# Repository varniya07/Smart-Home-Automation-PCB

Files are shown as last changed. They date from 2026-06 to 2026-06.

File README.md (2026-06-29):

# 🏠 Smart Home Automation PCB

<p align="center">
  
  
  
  
</p>

---

# 📖 Overview

This project is a custom-designed **ESP32-based Smart Home Automation PCB** created using **KiCad 9**.

The board integrates an ESP32 microcontroller with an AC-to-DC power supply, voltage regulation, relay driver circuit, UART programming interface, and user controls for reliable IoT-based home automation.

---

# ✨ Features

- ESP32-WROOM-32 Microcontroller
- HLK-PM03 AC to DC Converter
- AMS1117-3.3V Voltage Regulator
- Relay Driver Circuit
- Boot & Reset Buttons
- UART Programming Header
- Two-Layer PCB
- Compact Board Layout
- Mounting Holes

---

# 🛠 Software Used

- KiCad 9
- Git
- GitHub

---

# 🔩 Hardware Components

- ESP32-WROOM-32
- HLK-PM03 AC-DC Module
- AMS1117-3.3V
- Relay
- BC817 Transistor
- LEDs
- Resistors
- Capacitors
- Push Buttons
- UART Header

---

# 📷 Schematic

<p align="center">

</p>

---

# 📷 PCB Layout

<p align="center">
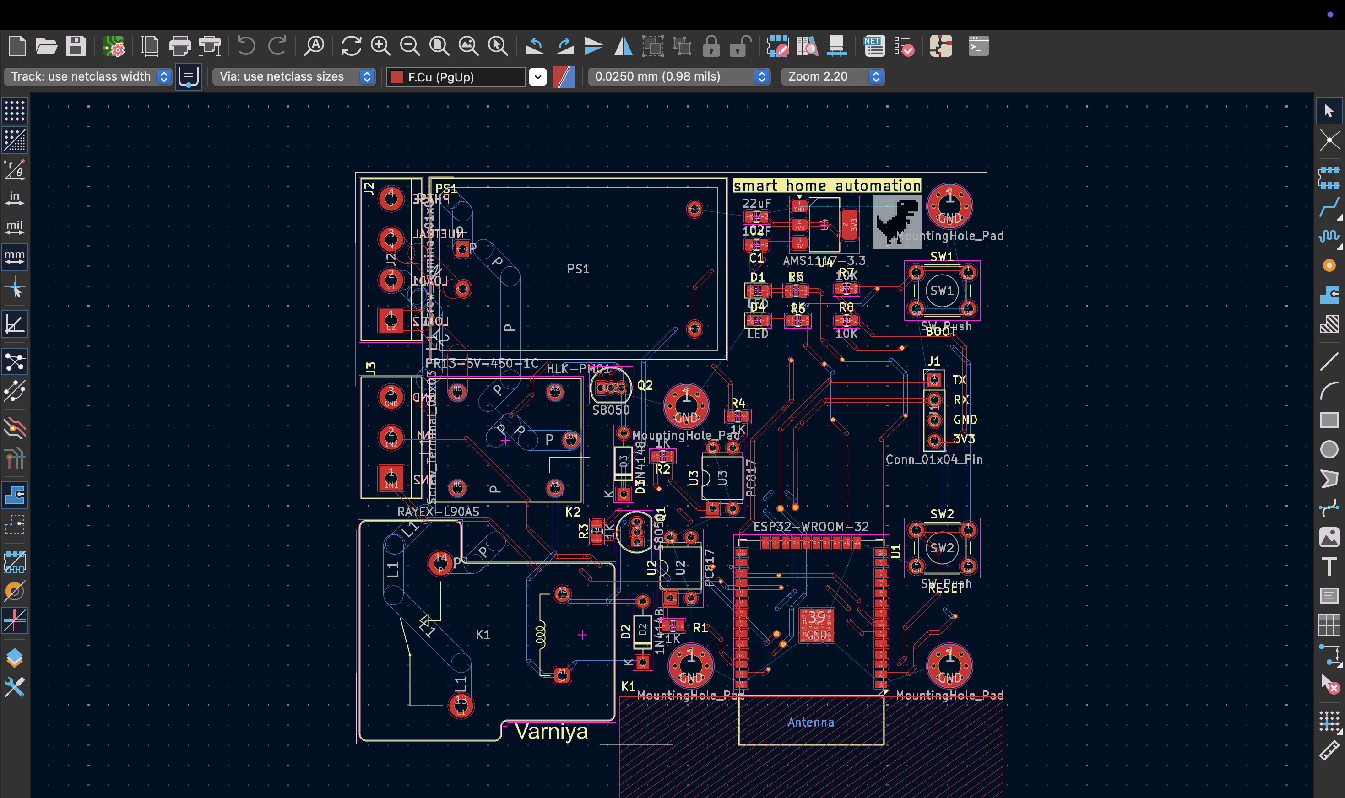
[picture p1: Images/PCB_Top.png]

</p>

---

# 📷 3D PCB View

<p align="center">
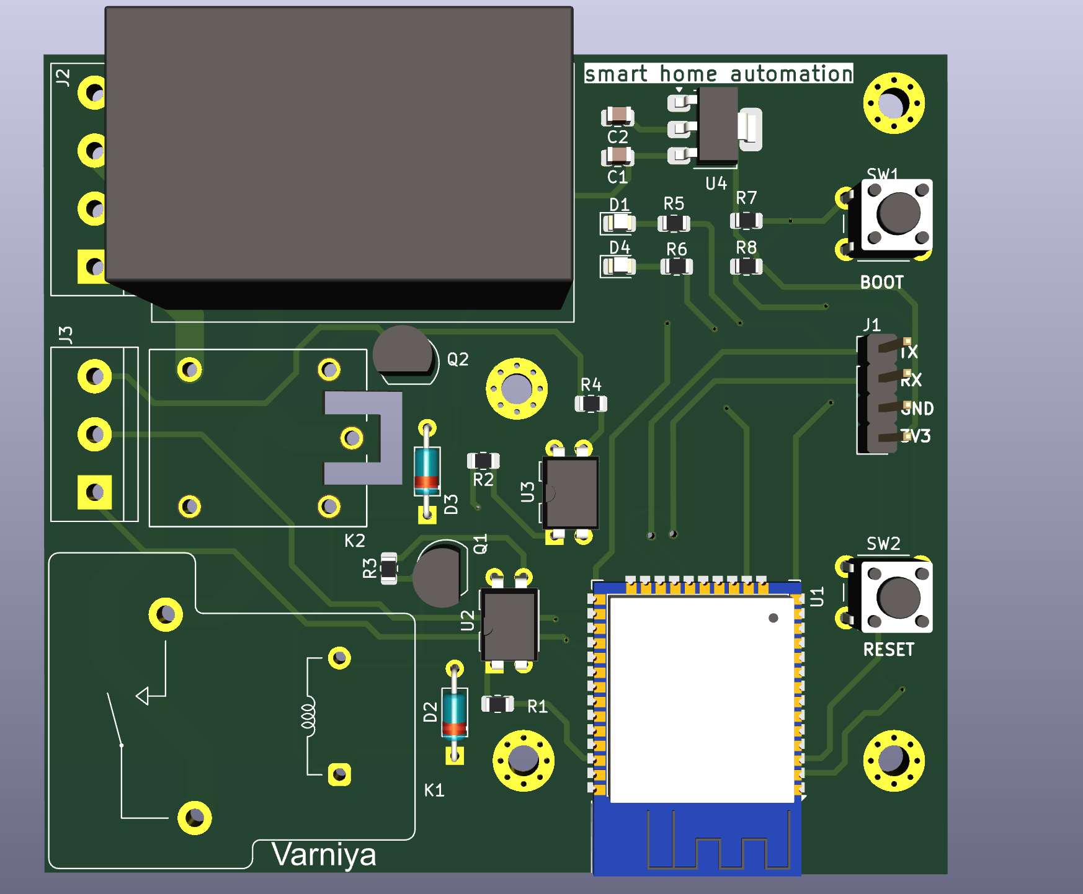
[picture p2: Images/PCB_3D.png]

</p>

---

# ⚙️ Working Principle

1. The AC mains supply is converted into regulated DC using the **HLK-PM03 AC-DC converter**.
2. The **AMS1117-3.3V** regulator provides a stable 3.3V supply for the ESP32.
3. The ESP32 receives commands through Wi-Fi.
4. GPIO pins control the relay driver transistor.
5. The relay switches external electrical appliances.
6. Boot and Reset buttons simplify programming and debugging.
7. The UART header enables firmware uploading and serial monitoring.

---

# 📂 Repository Structure

```text
Smart-Home-Automation-PCB
│
├── BOM/
│
├── Gerber/
│
├── Images/
│   ├── PCB_Top.png
│   ├── PCB_3D.png
│   └── smart home automation.svg
│
├── KiCad_Project/
│   ├── smart home automation.kicad_pcb
│   ├── smart home automation.kicad_pro
│   ├── smart home automation.kicad_prl
│   ├── smart home automation.kicad_sch
│   └── smart home automation-backups
│
└── README.md
```

---

# 📦 Gerber Files

The complete Gerber package required for PCB manufacturing is included in the **Gerber** folder.

Supported manufacturers include:

- JLCPCB
- PCBWay
- ALLPCB
- NextPCB

---

# 🚀 Applications

- Smart Home Automation
- IoT Systems
- Embedded Systems
- ESP32 Development
- PCB Design Learning
- Electronics Education

---

# 📚 Skills Demonstrated

- PCB Design using KiCad
- Schematic Capture
- Component Selection
- PCB Routing
- Design Rule Check (DRC)
- Gerber File Generation
- PCB Manufacturing Preparation
- Embedded Hardware Design

---

# 🔮 Future Improvements

- MQTT Integration
- Mobile Application
- Energy Monitoring
- OTA Firmware Updates
- Current & Voltage Sensing
- Voice Assistant Integration
- Smart Scheduling

---

# 👩‍💻 Author

## Varniya Bhatnagar

**B.E. Electronics & Communication Engineering**  
Panjab University

### Connect with me

- 📧 Email: **varniyaece@gmail.com**
- 💼 LinkedIn: https://www.linkedin.com/in/varniya-bhatnagar-1ab361327/
- 🐙 GitHub: https://github.com/varniya07

---

## ⭐ Support

If you found this project useful, consider giving it a ⭐ and following my GitHub profile for more Electronics, PCB Design, Embedded Systems, and VLSI projects.

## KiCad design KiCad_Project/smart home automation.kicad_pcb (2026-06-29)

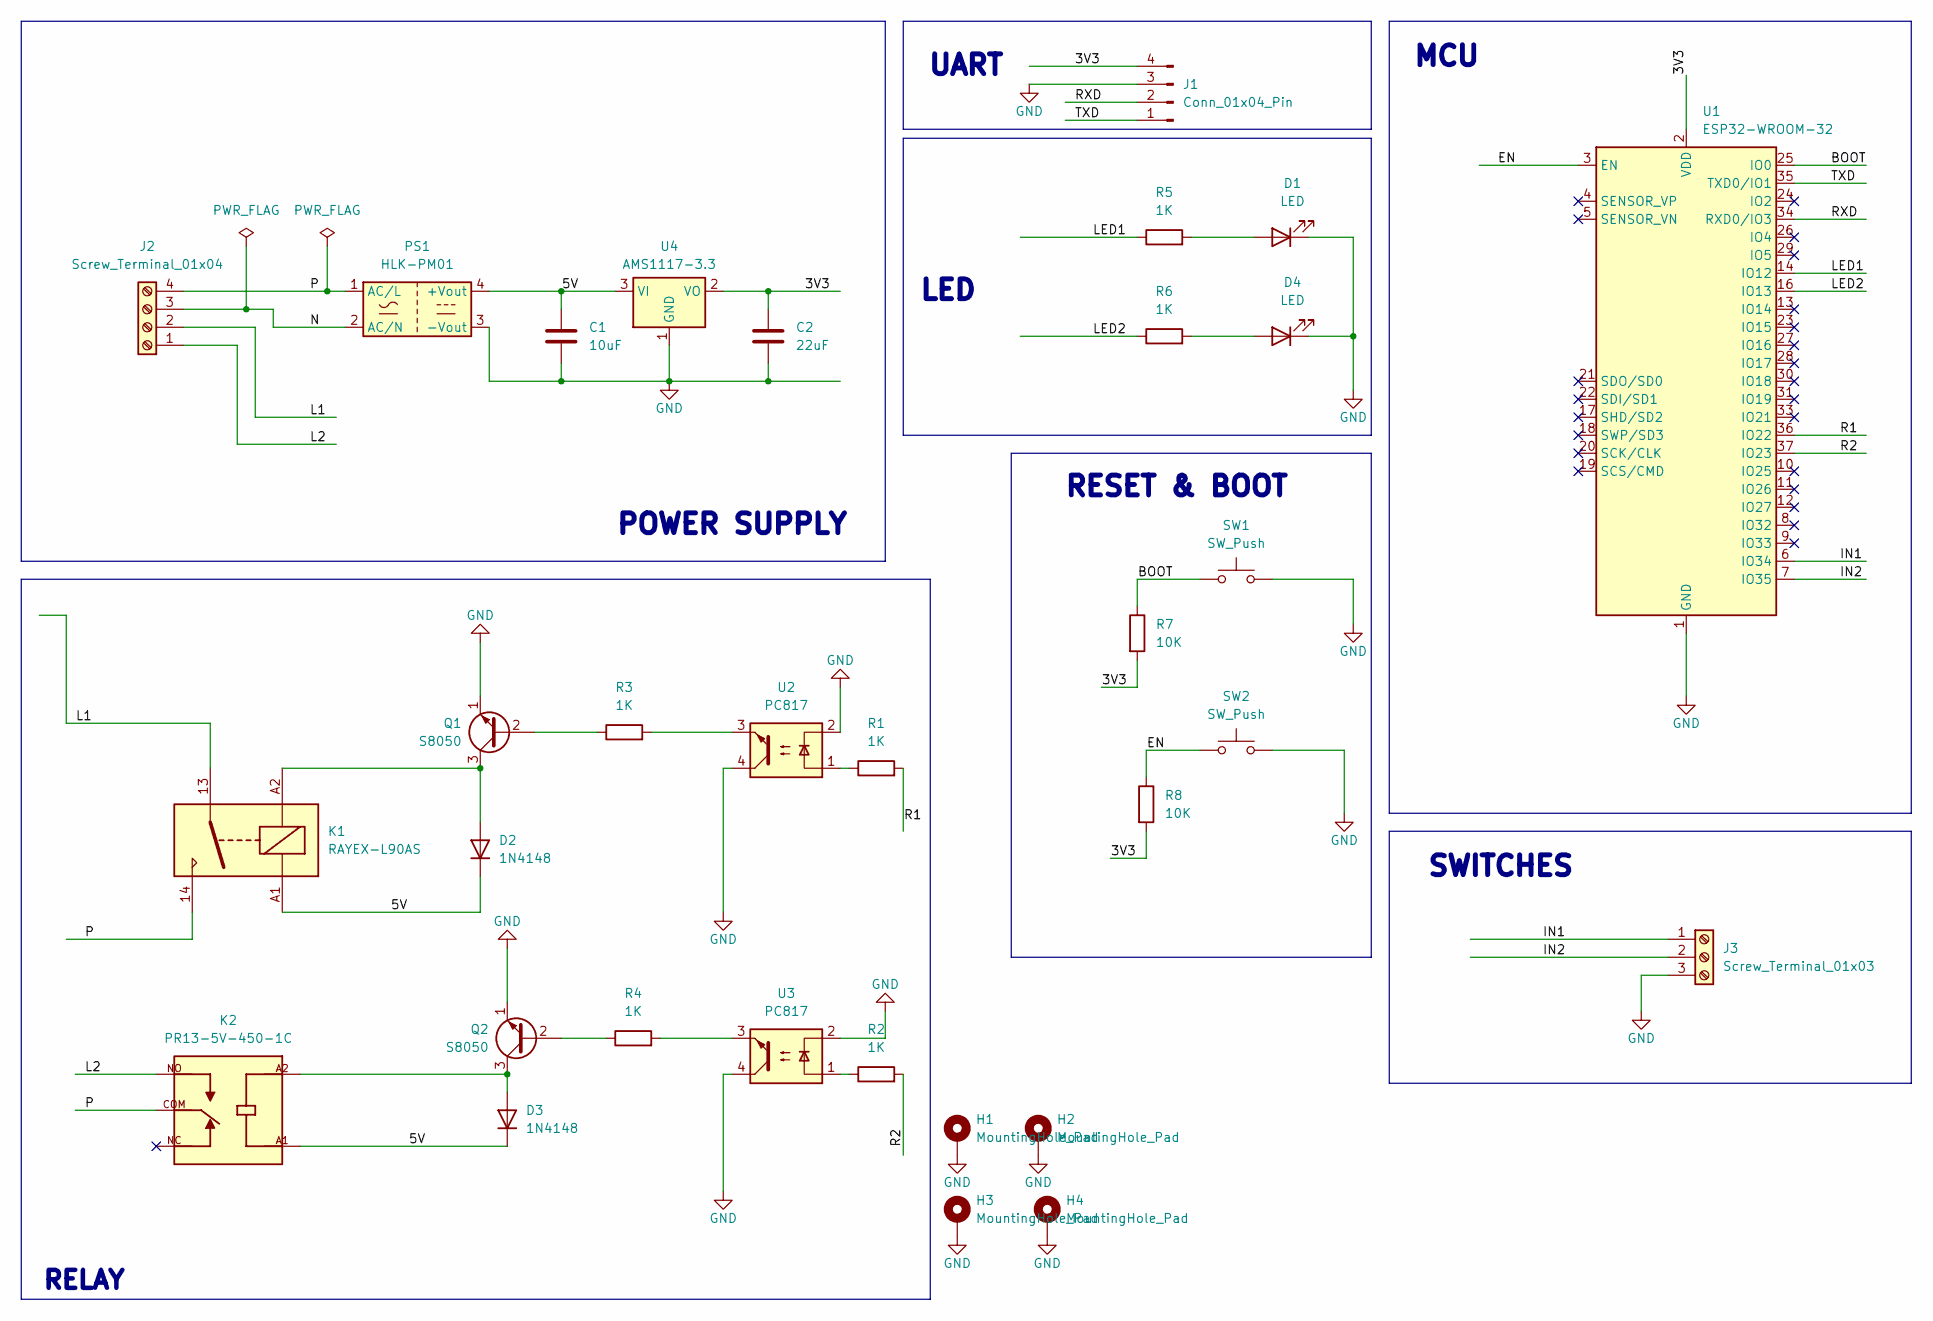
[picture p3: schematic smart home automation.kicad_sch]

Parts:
C1: 10uF; C_0805_2012Metric
C2: 22uF; C_0805_2012Metric
D1, D4: LED; LED_0805_2012Metric
D2, D3: 1N4148; D_DO-35_SOD27_P7.62mm_Horizontal
H1, H2, H3, H4: MountingHole_Pad; MountingHole_2.7mm_M2.5_Pad_Via
J1: Conn_01x04_Pin; PinHeader_1x04_P2.54mm_Vertical
J2: Screw_Terminal_01x04; TerminalBlock_bornier-4_P5.08mm
J3: Screw_Terminal_01x03; TerminalBlock_bornier-3_P5.08mm
K1: RAYEX-L90AS; Relay_SPST_RAYEX-L90AS
K2: PR13-5V-450-1C; RELAY_PR13-5V-450-1C; PARTREV 1.0
PS1: HLK-PM01; Converter_ACDC_Hi-Link_HLK-PMxx
Q1, Q2: S8050; TO-92_Inline
R1, R2, R3, R4, R5, R6: 1K; R_0805_2012Metric
R7, R8: 10K; R_0805_2012Metric
SW1, SW2: SW_Push; SW_PUSH_6mm
U1: ESP32-WROOM-32
U2, U3: PC817; DIP-4_W7.62mm
U4: AMS1117-3.3; SOT-223-3_TabPin2

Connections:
/3V3: C2.1, J1.4, R7.2, R8.2, U1.2 (VDD), U4.2 (VO)
/5V: C1.1, D2.1 (K), D3.1 (K), K1.A1, K2.A1, PS1.4 (+Vout), U4.3 (VI)
/BOOT: R7.1, SW1.1, U1.25 (IO0)
/EN: R8.1, SW2.1, U1.3 (EN)
/IN1: J3.1, U1.6 (IO34)
/IN2: J3.2, U1.7 (IO35)
/L1: J2.2, K1.13
/L2: J2.1, K2.NO
/LED1: R5.1, U1.14 (IO12)
/LED2: R6.1, U1.16 (IO13)
/N: J2.3, PS1.2 (AC/N)
/P: J2.4, K1.14, K2.COM, PS1.1 (AC/L)
/R1: R1.2, U1.36 (IO22)
/R2: R2.2, U1.37 (IO23)
/RXD: J1.2, U1.34 (RXD0/IO3)
/TXD: J1.1, U1.35 (TXD0/IO1)
GND: C1.2, C2.2, D1.1 (K), D4.1 (K), H1.1, H2.1, H3.1, H4.1, J1.3, J3.3, PS1.3 (-Vout), Q1.1 (E), Q2.1 (E), SW1.2, SW2.2, U1.1 (GND), U1.15 (GND), U1.38 (GND), U1.39 (GND), U2.2, U2.4, U3.2, U3.4, U4.1 (GND)
unnamed: D1.2 (A), R5.2
unnamed: D2.2 (A), K1.A2, Q1.3 (C)
unnamed: D3.2 (A), K2.A2, Q2.3 (C)
unnamed: D4.2 (A), R6.2
unnamed: Q1.2 (B), R3.1
unnamed: Q2.2 (B), R4.1
unnamed: R1.1, U2.1
unnamed: R2.1, U3.1
unnamed: R3.2, U2.3
unnamed: R4.2, U3.3

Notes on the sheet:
UART
SWITCHES
RESET & BOOT
RELAY
MCU
LED
POWER SUPPLY

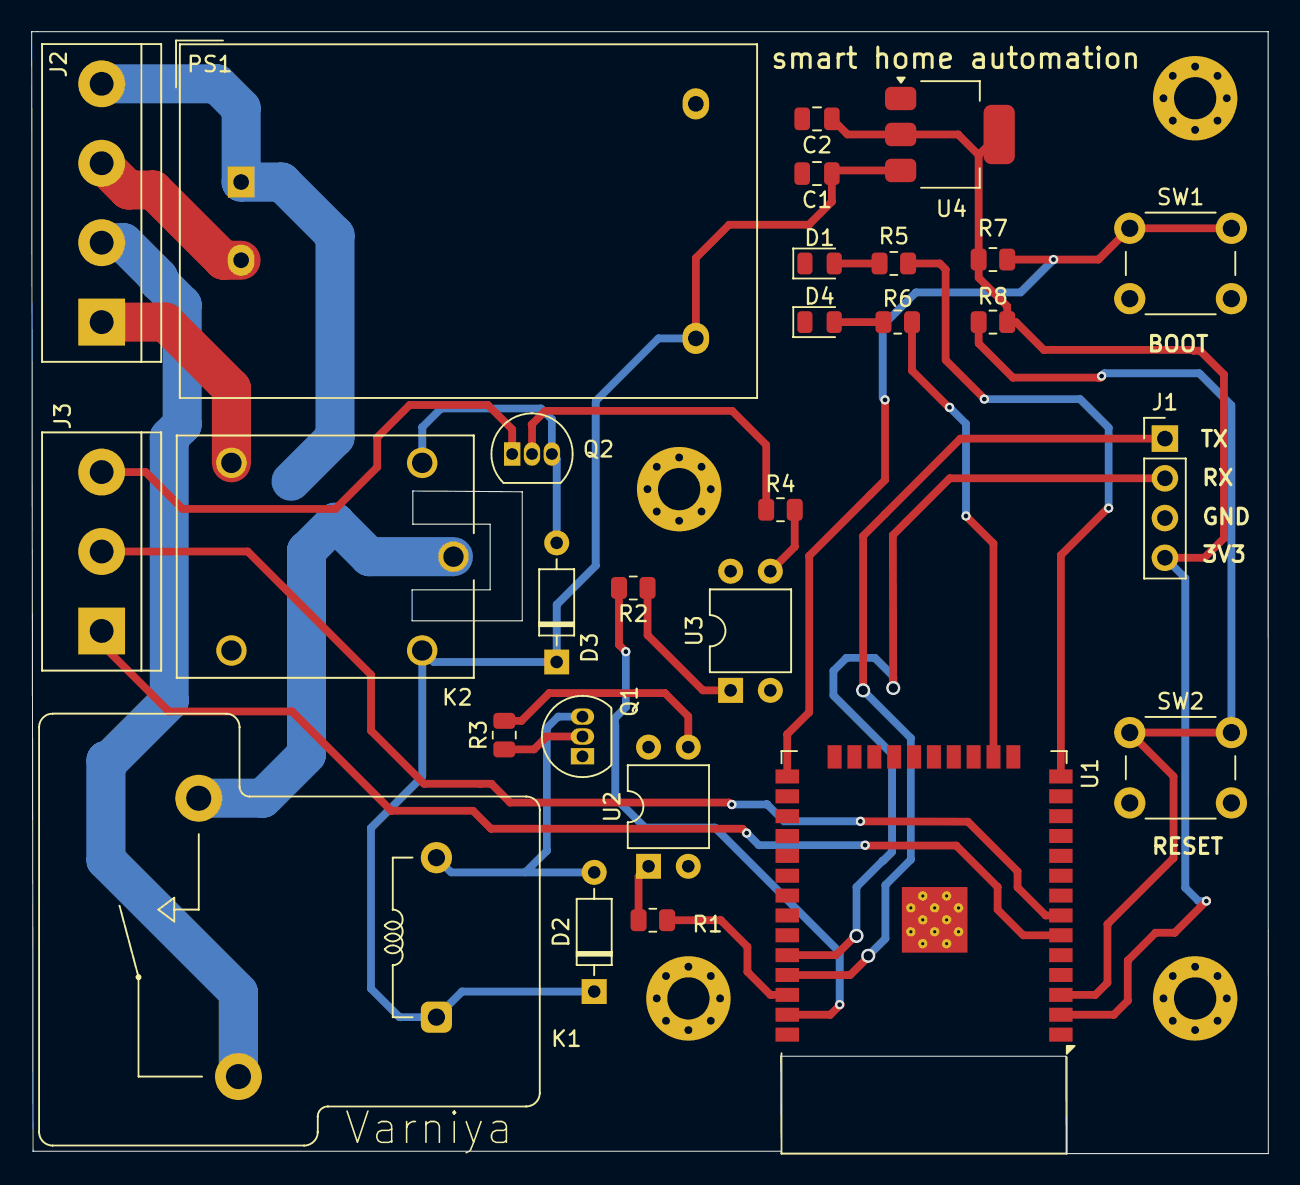
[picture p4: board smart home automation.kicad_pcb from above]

Board: 2 copper layers, 79.1 x 71.8 mm, 32 parts (0 on the bottom side), 27 nets.
